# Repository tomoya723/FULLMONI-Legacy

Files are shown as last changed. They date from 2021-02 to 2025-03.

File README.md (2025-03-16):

### FULL-MONI フルモニ
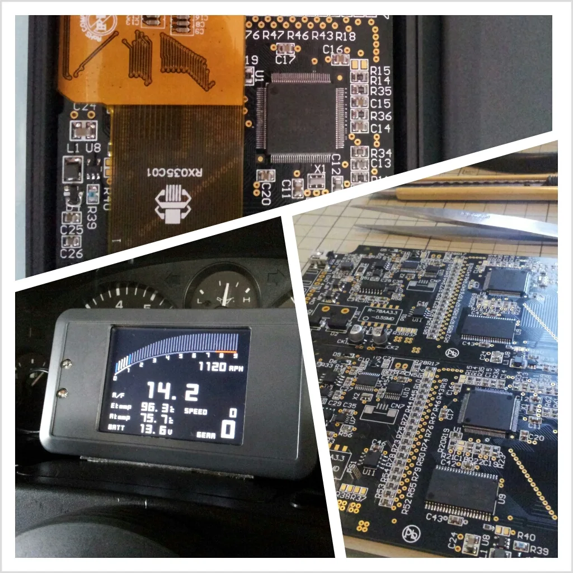
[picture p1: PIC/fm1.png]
fm1

## ０．注記
 - このリポジトリは過去に開発を行ったものを参考公開しています。
 - 回路に含む電子部品はディスコンも多く、再生産は困難です。
 - ファームウェアの更新の予定もありません。
## １．フルモニとは
 - フルコンモニターの略称で、「フルモニ」。
 - 各種フルコン（対応機種随時予定）やＤＥＦＩのコントロールユニットⅠ/Ⅱから取得したデータを
 - ３．５インチＴＦＴ液晶に数値やグラフとしてリアルタイム表示します。

 - 各データの取得は、
 - フルコンからのデータは、ＣＡＮまたはＲＳ２３２Ｃ信号ケーブルを接続し、
 - ＤＥＦＩコントロールユニットⅠ/Ⅱからのデータは、
 - フルモニ専用のメータリンクケーブルを接続することで、データを受信します。

 - 表示データはそれぞれの表示選択や、ピークホールド表示、ワーニング表示を行います。

## ２．設計概要
 - 基板　　:　３．５インチＴＦＴ液晶を備えた基板を設計する。
 - ケース　:　タカチ電機工業製ＬＣＳ形シリコンケース付プラスチックケースを使用。
 -  　　　　　液晶、ＬＥＤ及び入力端子部分の切削加工を行う。

## ３．ハードウェア仕様
 - １２Ｖバッテリー車向け制御電源（ＤＣ＋４．７５～＋３２Ｖ　→　内部電源＋３．３Ｖ）
 - タッチパネルＩＦ付３．５インチＴＦＴ液晶
 - 液晶バックライト用電源(調光機能付)
 - ＣＰＵ　ルネサステクノロジ　Ｈ８ＳＸ１６５５　４８ＭＨｚ
 - 外部ＳＲＡＭ　４Ｍｂｉｔ（おもに液晶用ビデオバッファ用途）
 - ＣＡＮ２．０Ｂ送受信　　　１チャンネル
 - ＲＳ２３２Ｃ送受信　　　　１チャンネル（ＦＣロガー接続選択機能付）
 - ＤＥＦＩ用Ｉ／Ｆ受信のみ　１チャンネル
 - 超高輝度ＬＥＤ（赤・橙）
 - ケース内ブザー
 - タッチパネルＩ／Ｆ
 - ＳＰＩフラッシュＲＯＭ　４ｋｂｉｔ

## ４．回路設計
 - 2013年1月28日更新
 - SCH : [FULLMONI_revC_SCH_20130128_101.pdf](https://github.com/tomoya723/FULLMONI-Legacy/blob/4514685d8f7103bcbfc3824f94381c39d037f4da/Hardware/FULLMONI_revC_SCH_20130128_101.pdf)<br>

## ５．基板設計
 - 2013年3月6日更新
 -  PCB : [FULLMONI_revC_PCB_20130306_101.pdf](https://github.com/tomoya723/FULLMONI-Legacy/blob/c4a8cc1ee19b74c6463b97665e4f9444e0cc6ba2/Hardware/FULLMONI_revC_PCB_20130306_101.pdf)<br>

## ５．ケース設計
 タカチ LC135-Nをベースに加工
 Case data: [LCケース加工図面20121030.pdf](https://github.com/tomoya723/FULLMONI-Legacy/blob/f6450ae8e5cbf89b6b0861b6293d36d16016387c/Hardware/LC%E3%82%B1%E3%83%BC%E3%82%B9%E5%8A%A0%E5%B7%A5%E5%9B%B3%E9%9D%A2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)<br>

## ６．基板作成仕様
 - 外形１３０．０ｍｍ×６６．０ｍｍ（但し外形はルーター加工特殊形状）
 - 板厚１．６ｍｍ
 - ＦＲ４(ガラスエポキシ)
 - 構成　４層（信号２層/電源２層）
 - 部品実装　片面　白色
 - レジスト　両面　黒色
 - 最小パタン幅０．２ｍｍ／最小クリアランス０．２ｍｍ
 - 最小穴径０．５ｍｍ
 - 無電解金フラッシュ仕上げ

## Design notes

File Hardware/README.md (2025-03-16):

# FULLMONI-Legacy：Hardware
# Schematic & PCB Files
 SCH : [FULLMONI_revC_SCH_20130128_101.pdf](https://github.com/tomoya723/FULLMONI-Legacy/blob/4514685d8f7103bcbfc3824f94381c39d037f4da/Hardware/FULLMONI_revC_SCH_20130128_101.pdf)<br>
 PCB : [FULLMONI_revC_PCB_20130306_101.pdf](https://github.com/tomoya723/FULLMONI-Legacy/blob/c4a8cc1ee19b74c6463b97665e4f9444e0cc6ba2/Hardware/FULLMONI_revC_PCB_20130306_101.pdf)<br>
 Gerver data: [CAM for FULLMONI_revC_20130306](https://github.com/tomoya723/FULLMONI-Legacy/tree/5013744d0d0d1694fd1f57bb33fa13641ba547d0/Hardware/CAM%20for%20FULLMONI_revC_20130306)<br>
 Metalmask data: [CAM for FULLMONI_revC_20130905_metalmask](https://github.com/tomoya723/FULLMONI-Legacy/tree/95ea076388679fc861d6b10b5c2362134d616c25/Hardware/CAM%20for%20FULLMONI_revC_20130905_metalmask)<br>
 Case data: [LCケース加工図面20121030.pdf](https://github.com/tomoya723/FULLMONI-Legacy/blob/f6450ae8e5cbf89b6b0861b6293d36d16016387c/Hardware/LC%E3%82%B1%E3%83%BC%E3%82%B9%E5%8A%A0%E5%B7%A5%E5%9B%B3%E9%9D%A2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)<br>

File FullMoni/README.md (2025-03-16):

# FULLMONI-Legacy : Firmware
## Development environment
- Renesas HEW
- H8SX Compiler
## State Machine Flow
 The FILLMONI-Legacy firmware is controlled by the following state machine flow in the main loop.<br>


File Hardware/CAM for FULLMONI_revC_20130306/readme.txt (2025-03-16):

<FILES>
readme.txt     : This file
FULLMONI.apr   : Apertures List
FULLMONI.GTL   : Top (component side) layer
FULLMONI.GTO   : Top Overlay (silkscreen)
FULLMONI.GTS   : Top Solder mask layer (Solder stop component side)
FULLMONI.GP1   : Mid plane1(GND)(Negative)
FULLMONI.GP2   : Mid plane2(POWER)(Negative)
FULLMONI.GBL   : Bottom (solder side) layer
FULLMONI.GBS   : Bottom Solder mask layer (Solder stop solder side)
FULLMONI.GM2   : Mechanical layers (Outline)
FULLMONI.GD1   : Drill tools
FULLMONI.GG1   : Drill guide
FULLMONI.DRR   : NCDrillReport
FULLMONI.DRL   : NCDrillOutput(EIA FILE)
FULLMONI.TXT   : NCDrillOutput(ASCII FILE)
FULLMONI.PDF   : Layer view

<LAYER STACK ORDER>
(top side)
   1. FULLMONI.GTL (Top layer)
   2. FULLMONI.GP1 (Mid plane 1)
   3. FULLMONI.GP2 (Mid plane 2)
   4. FULLMONI.GBL (Bottom layer)
(bottom side)

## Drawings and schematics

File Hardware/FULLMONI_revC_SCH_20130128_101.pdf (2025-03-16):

1 | 2 | 3 | 4 | 5 | 6 | 7 | 8

A

B

C

D

1 | 2 | 3 | 4 | 5 | 6 | 7 | 8

D

C

B

A

Title:

Size: | Number:
Date:

Revision:
Sheet of

A3

Designer:

0 3

Full-com Monitor

### 1 B

28-Jan-2013

tomoya

RESET

RxD6

RxD5
TxD5

RxD0
TxD0

SCK0

CS_CAN

INT_CAN
BL_PWM

RS

D[0-15]
A[1-18]

RD

CS2-A
RD/WR
CS1
LHWR
LLWR

TxD4
RxD4
SCK4
TP_CS

LCD_RST

SDA0
SCL0

INT_TP

FC_MODE

FULLMONI_1
FULLMONI_1.Sch

RxD5
TxD5
CS_CAN
SCK0
RxD0
TxD0
RESET
INT_CAN
BL_PWM
RxD6
FC_MODE

FULLMONI_2
FULLMONI_2.Sch

RD
LCD_RST
RS
CS2-A
RD/WR
CS1
LHWR
LLWR
D[0-15]
A[1-18]
TxD4
RxD4
SCK4
TP_CS
INT_TP
SDA0
SCL0

FULLMONI_3
FULLMONI_3.Sch

# P-O-R

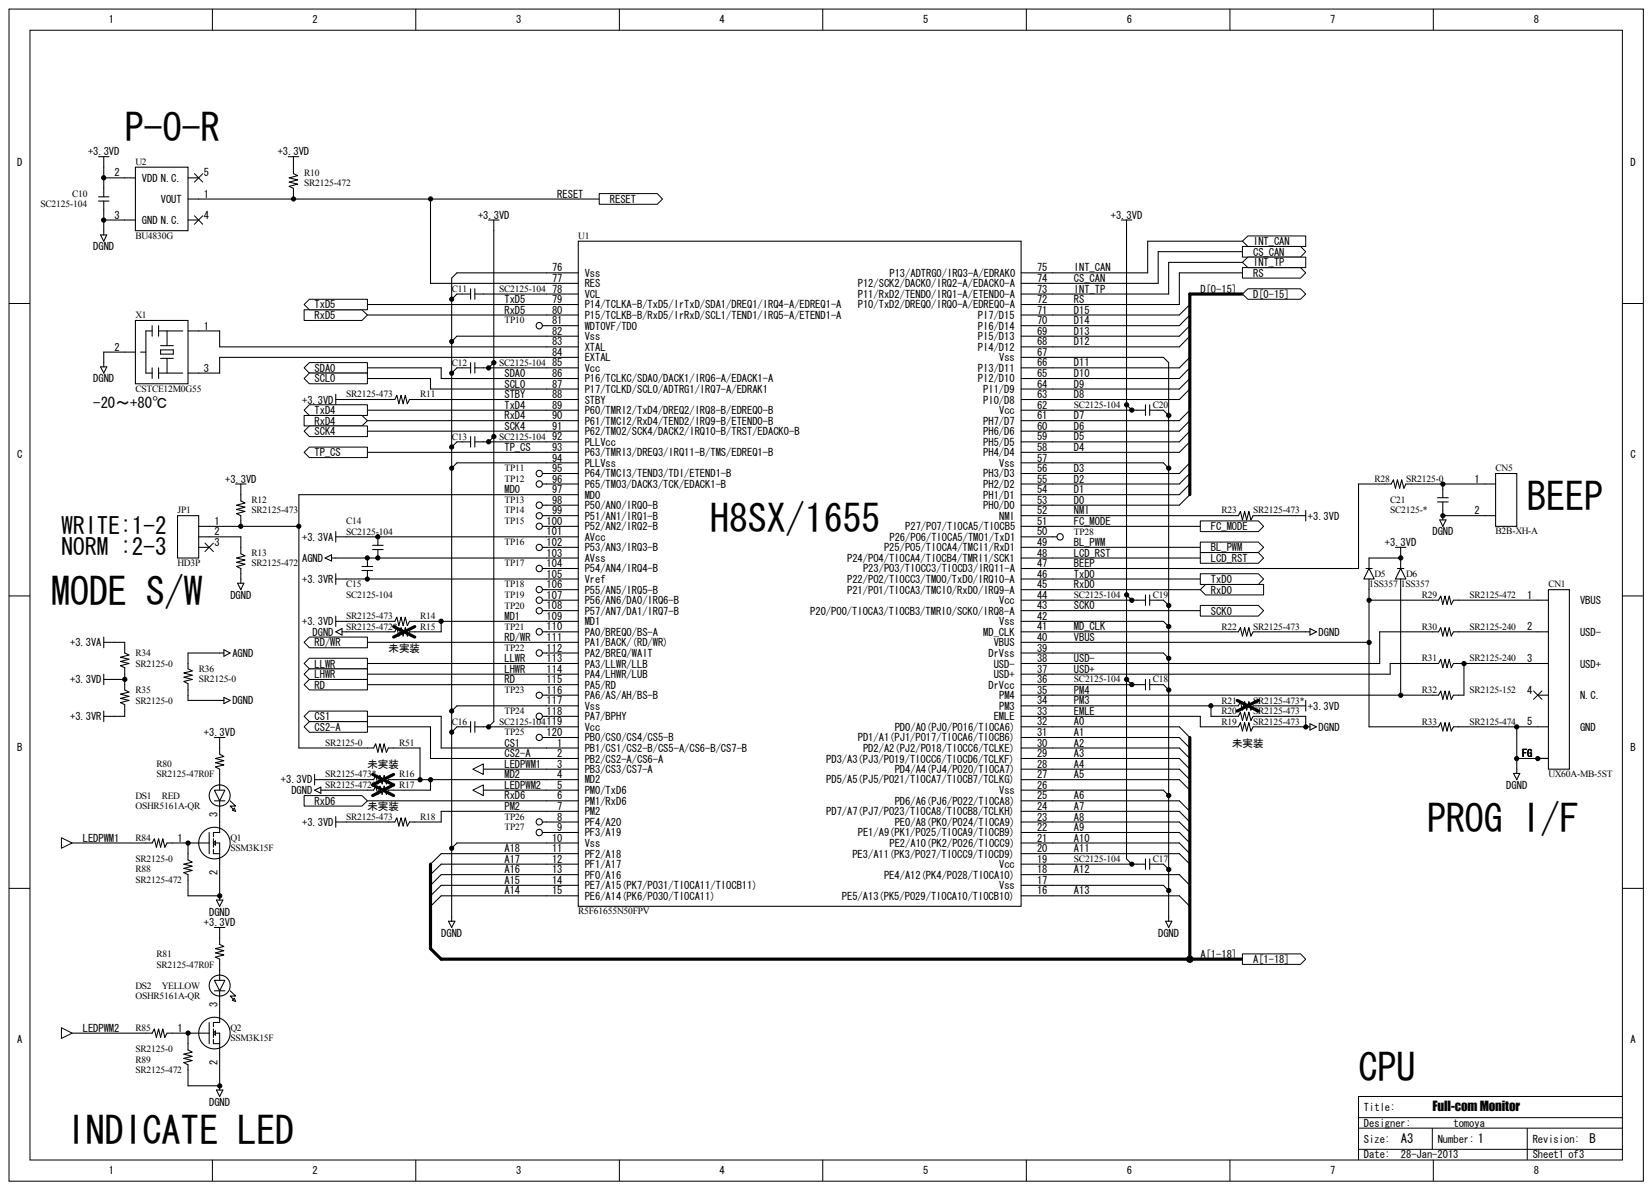
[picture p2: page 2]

# POWER

# POWER

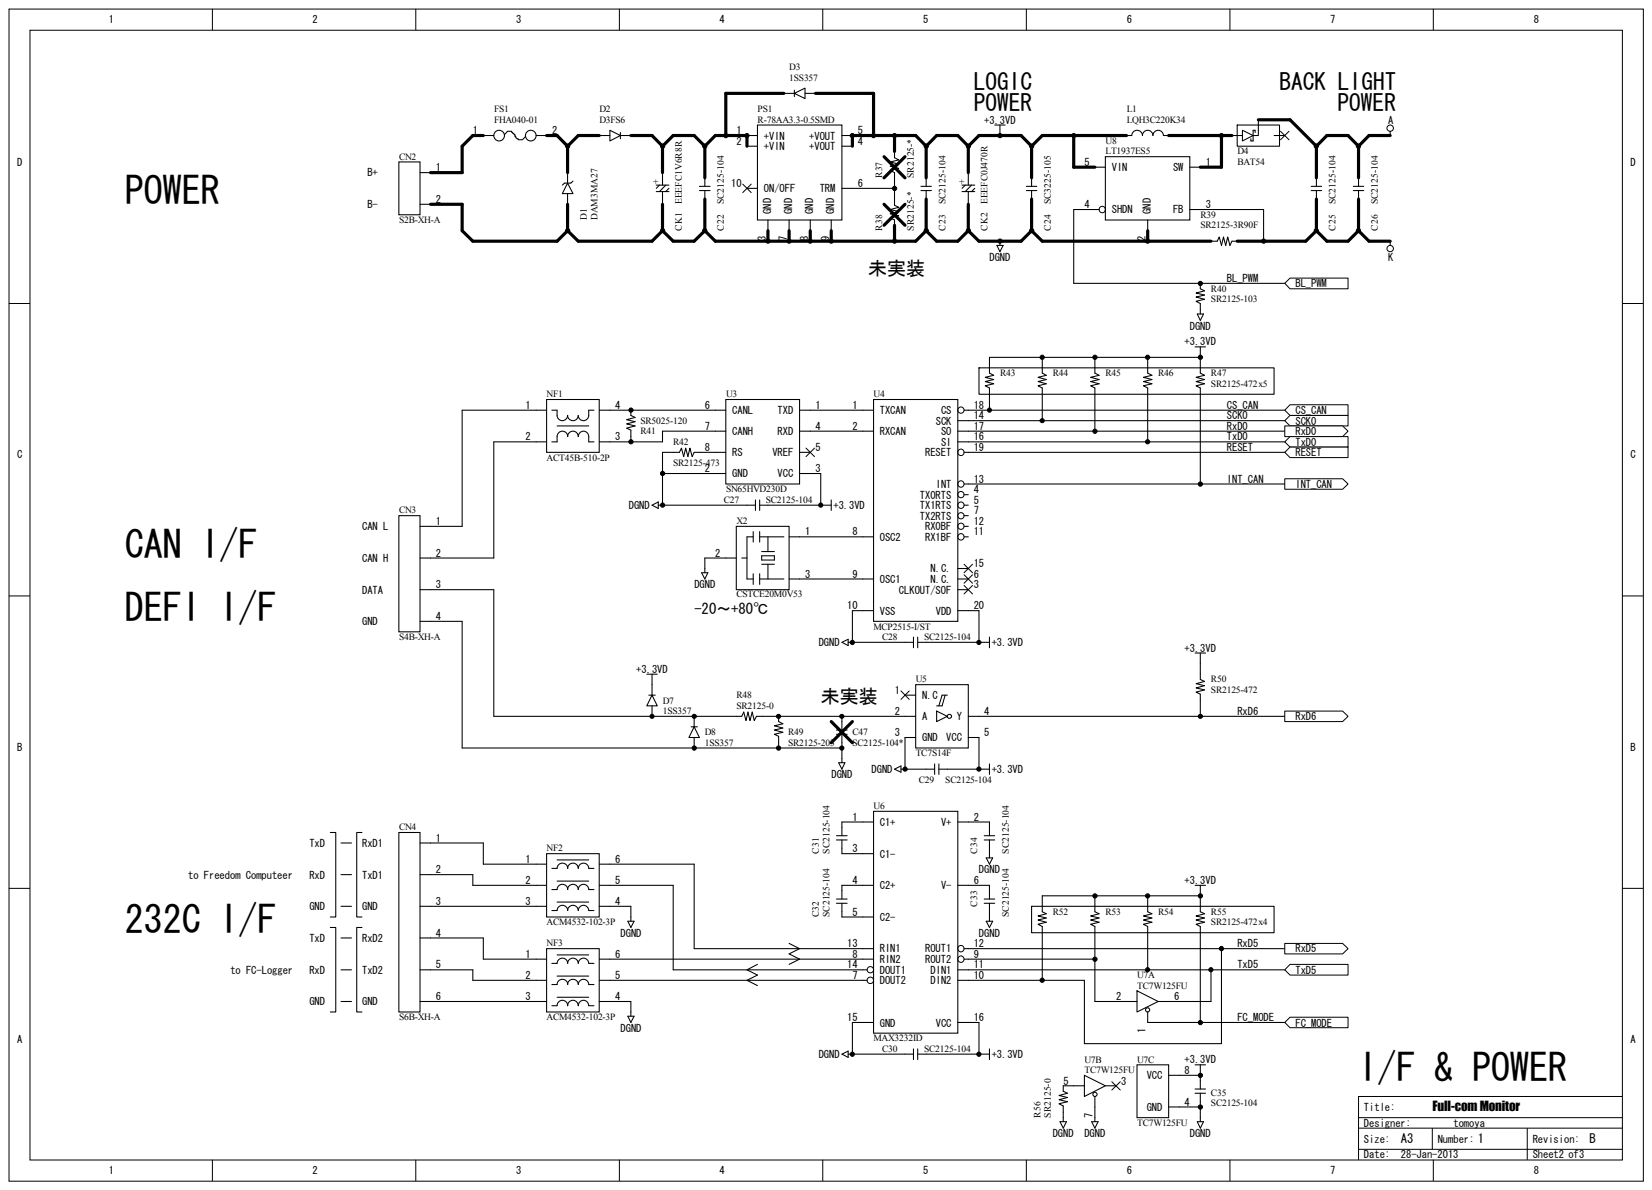
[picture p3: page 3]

LCD I/F | SRAM

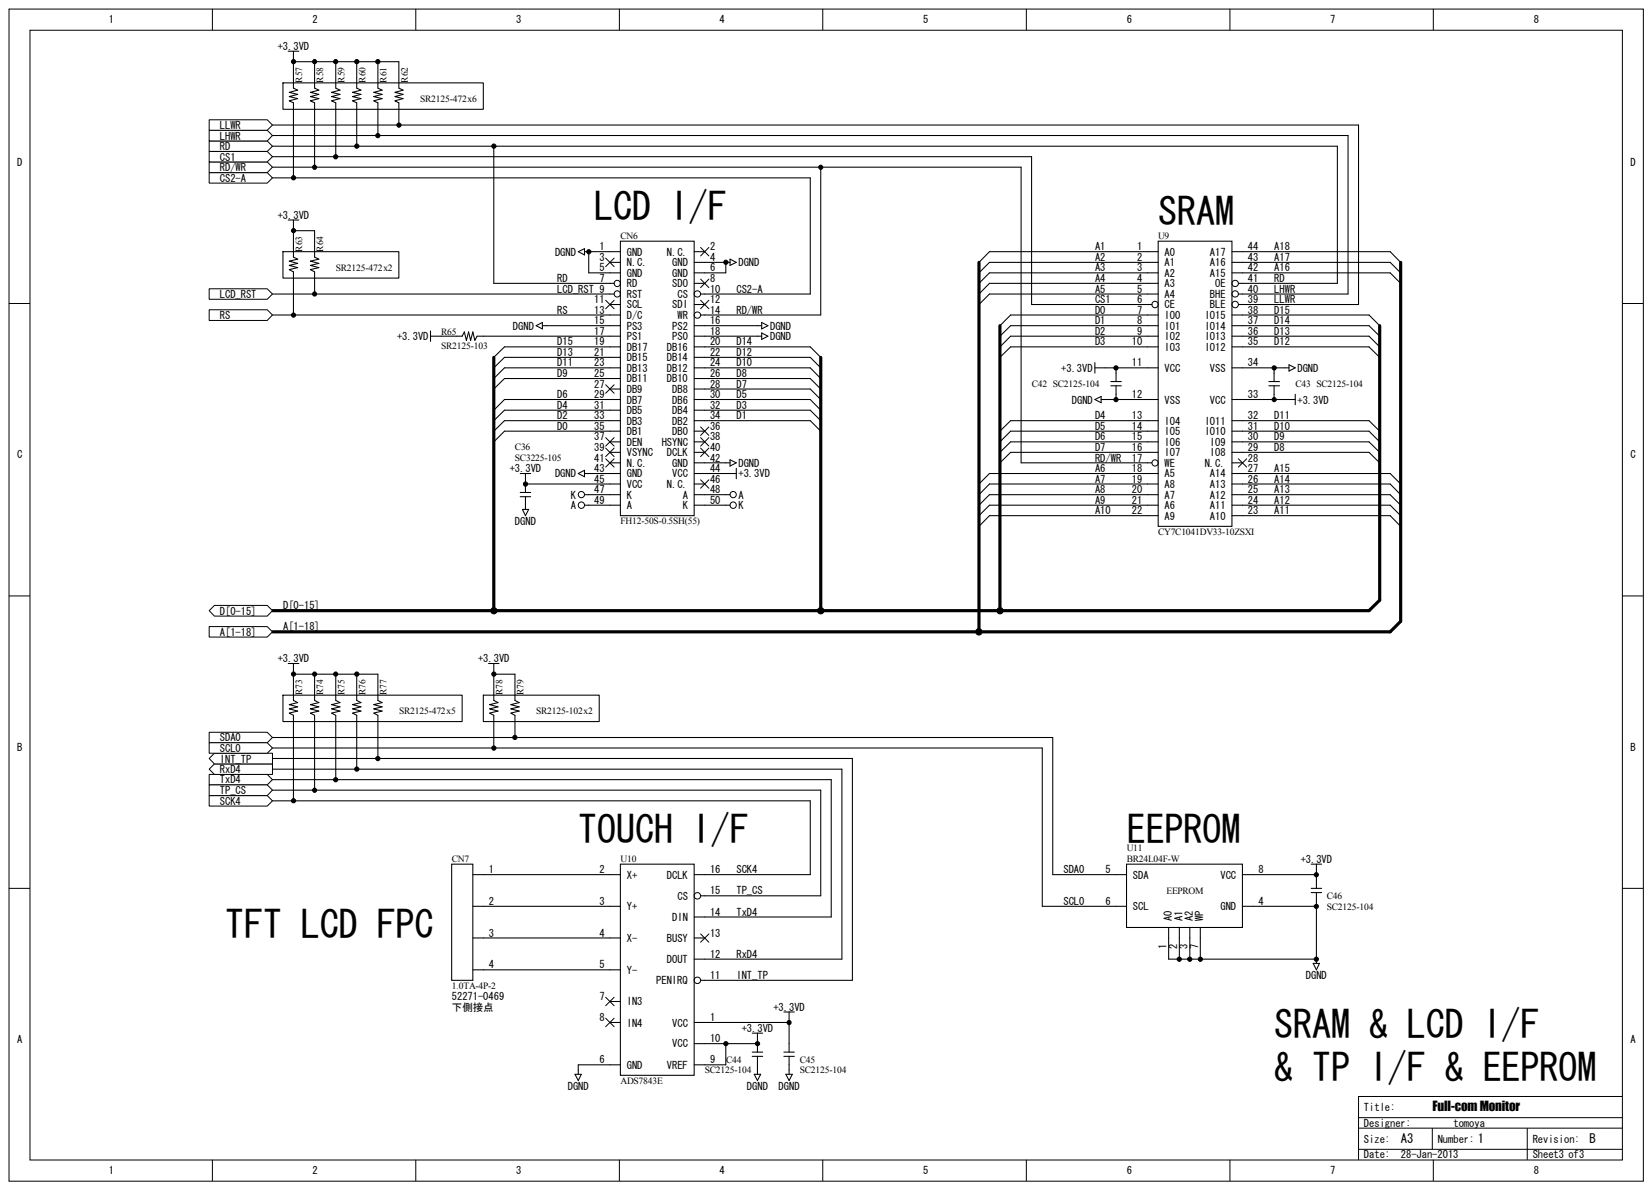
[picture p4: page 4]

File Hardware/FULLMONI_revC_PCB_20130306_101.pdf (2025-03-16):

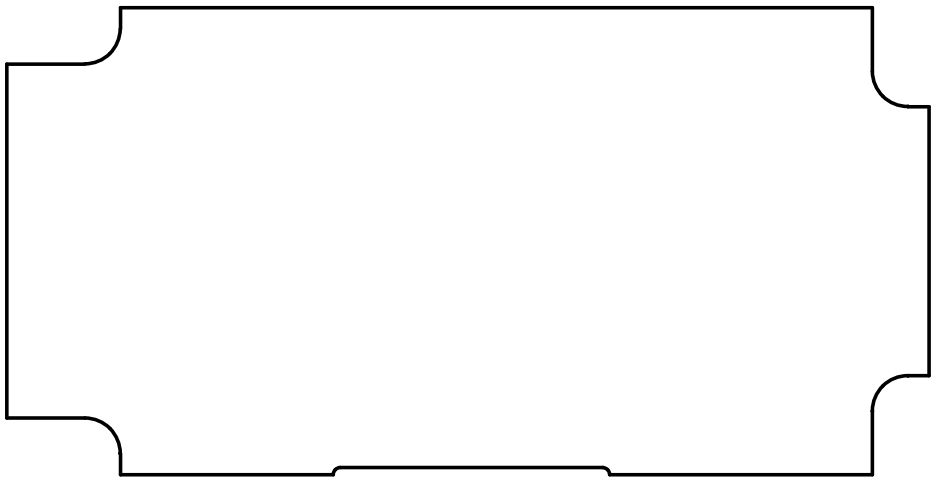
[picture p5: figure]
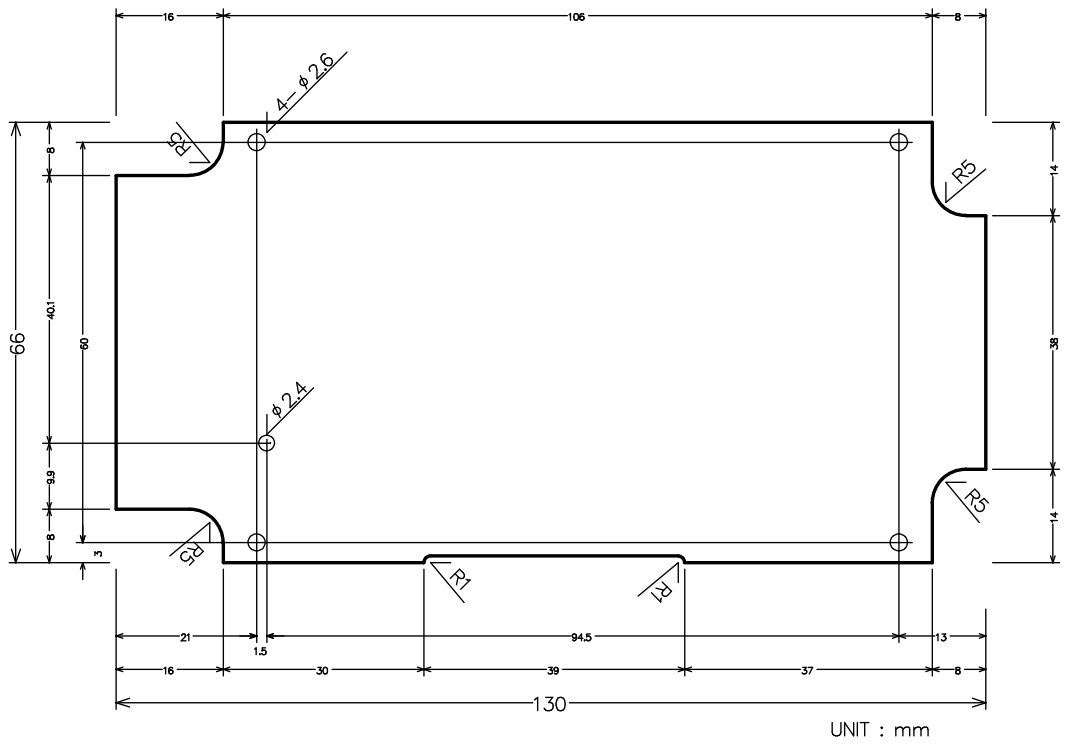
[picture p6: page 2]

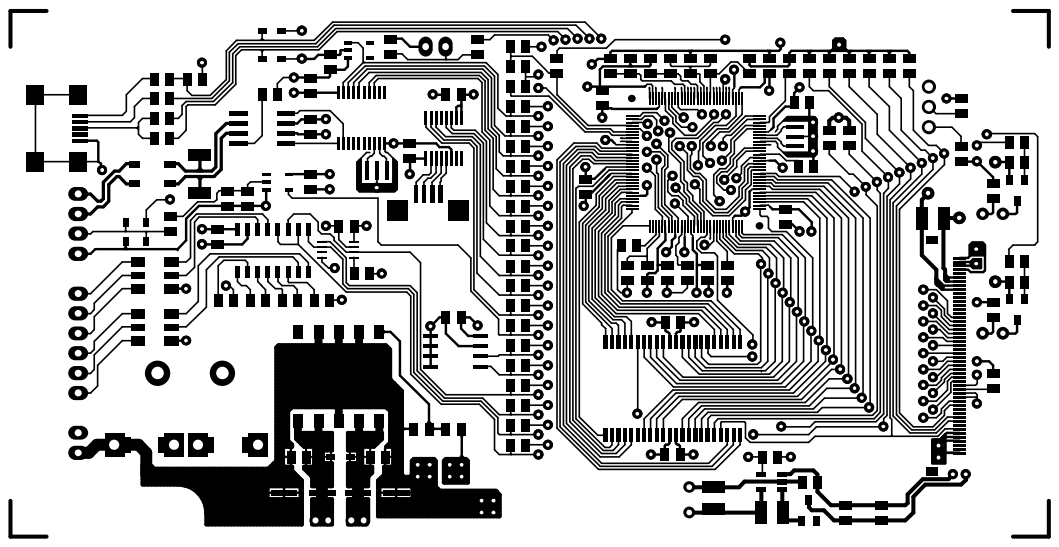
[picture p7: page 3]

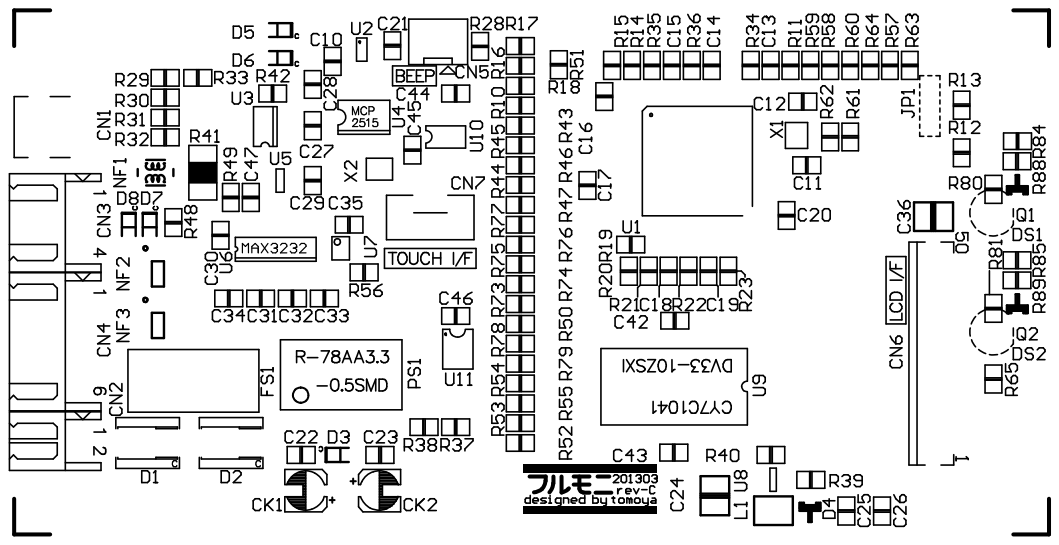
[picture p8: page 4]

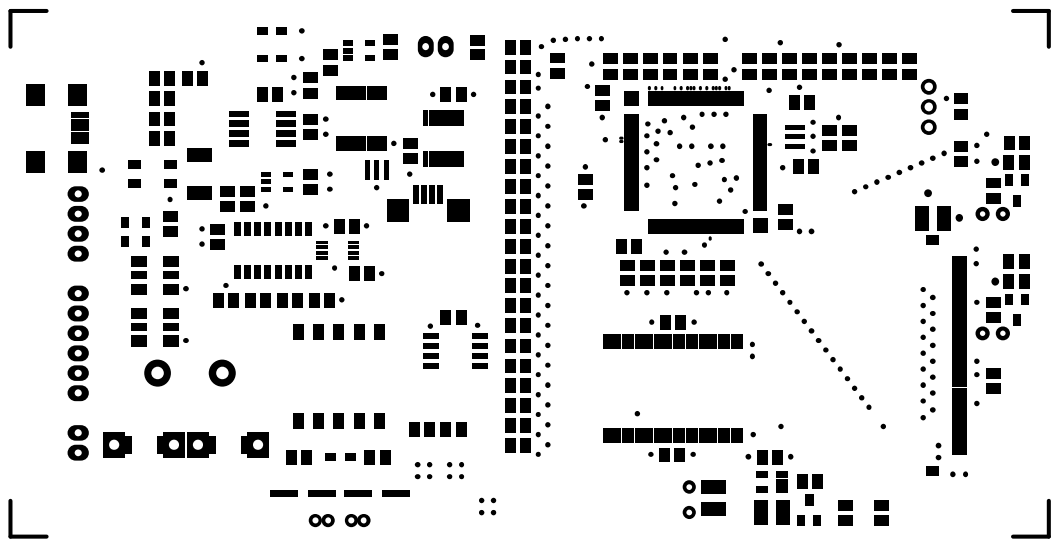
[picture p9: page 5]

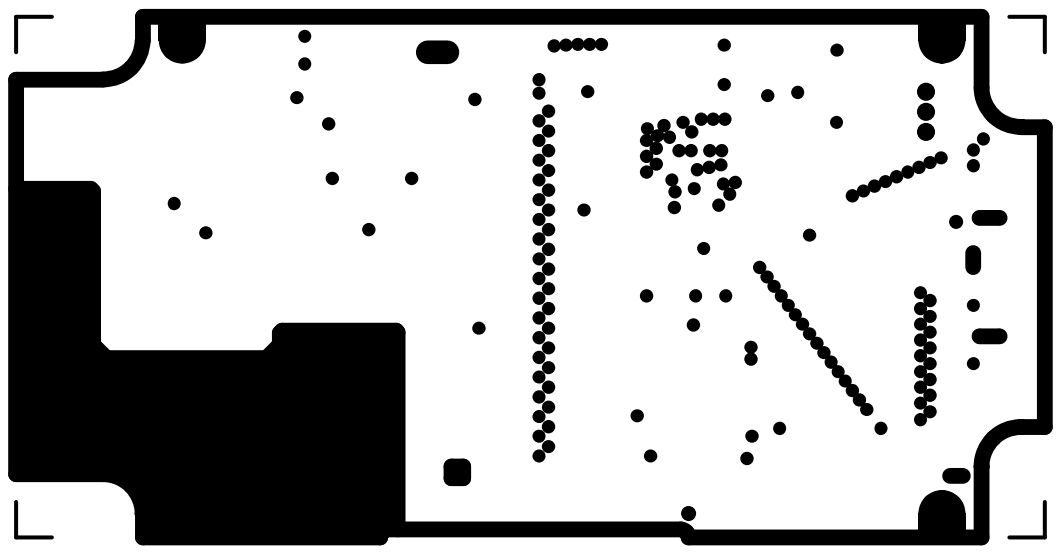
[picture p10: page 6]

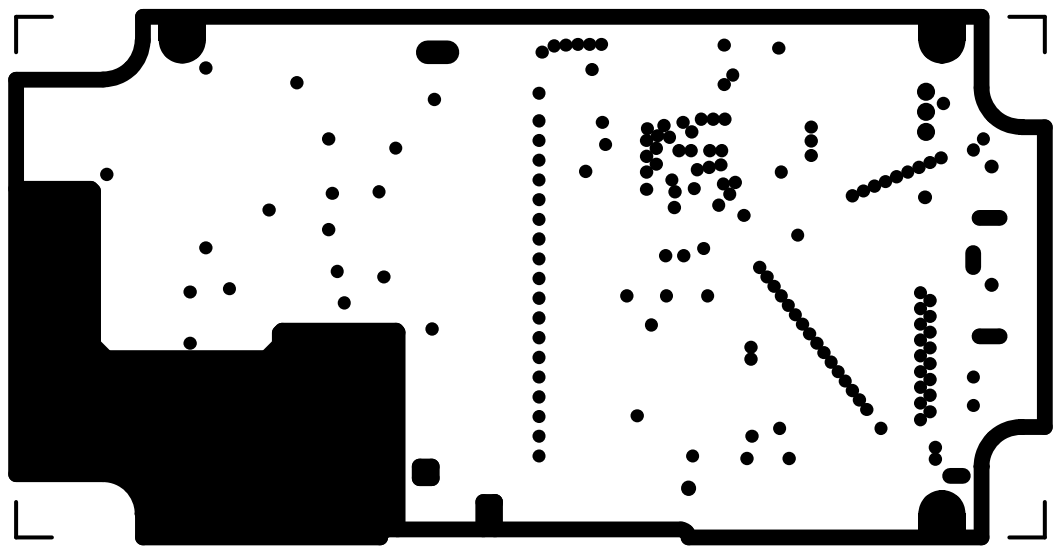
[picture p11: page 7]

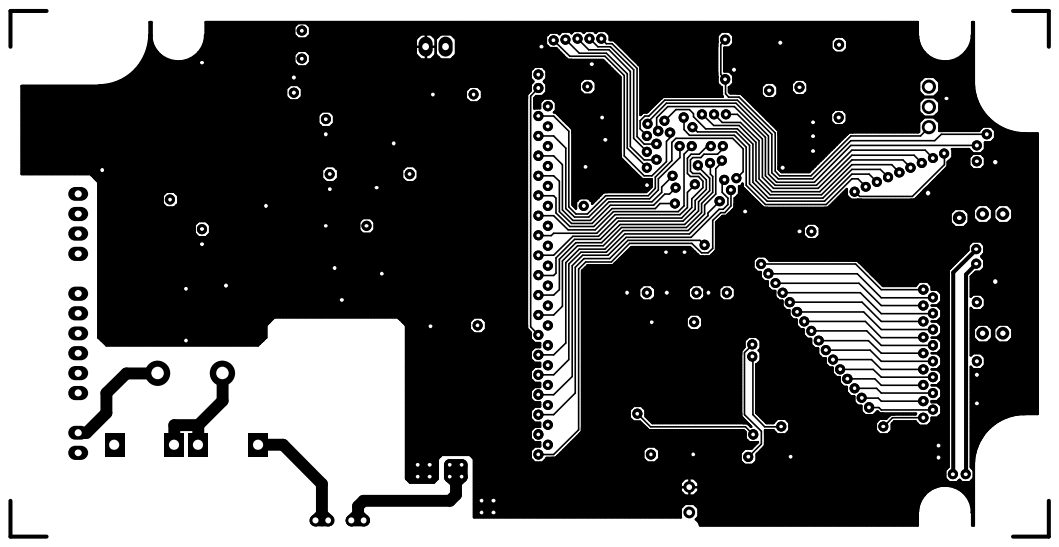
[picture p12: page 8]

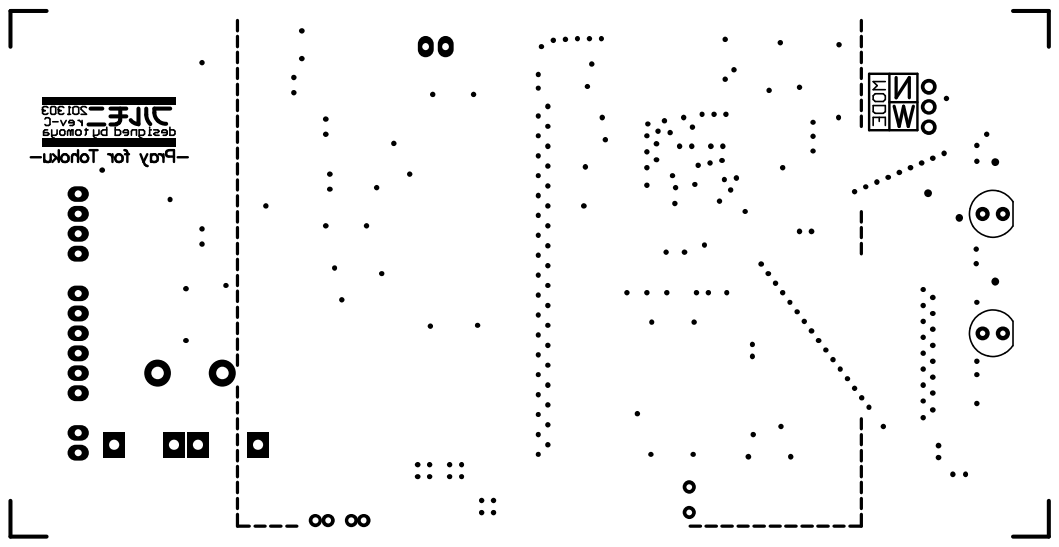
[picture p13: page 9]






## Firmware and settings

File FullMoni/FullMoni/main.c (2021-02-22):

// --------------------------------------------------------------------
// Copylight (C) 2021, Tomoya Sato( https://blog.goo.ne.jp/nacci_tomoya )
//
// This file is part of FullMoni firmwere.
//
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
// filename		:	main.c
// brief		:	FullMoni rev.C メインルーチン
// author		:	Tomoya Sato
// update		:	2021/02/21
// version		:	1.06
// --------------------------------------------------------------------

// --------------------------------------------------------------------
// プロトタイプ宣言
// --------------------------------------------------------------------
void main(void);
#ifdef __cplusplus
extern "C" {
void abort(void);
}
#endif

// --------------------------------------------------------------------
// システムヘッダファイル
// --------------------------------------------------------------------
//#include <machine.h>

// --------------------------------------------------------------------
// ユーザーヘッダファイル
// --------------------------------------------------------------------
#include "dataregister.h"
#include "iodefine.h"
#include "init_system.h"
#include "TFTLCD35.h"
#include "CAN2515.h"
#include "spi.h"
#include "state_control.h"

// --------------------------------------------------------------------
// グローバル変数宣言
// --------------------------------------------------------------------
volatile char version[5] = "v1.06";

// --------------------------------------------------------------------
// グローバル構造体宣言
// --------------------------------------------------------------------
volatile e2p_data_t			g_e2p_data;
volatile CAN_data_t			g_CAN_data;
volatile MoTeC1_data_t		g_MoTeC1_data;
volatile Haltech1_data_t	g_Haltech1_data;
volatile Haltech2_data_t	g_Haltech2_data;
volatile Freedom2_data_t	g_Freedom2_data;
volatile Megasquirt1_data_t	g_Megasquirt1_data;

// --------------------------------------------------------------------
// メインルーチン
// --------------------------------------------------------------------
void main(void)
{
	// --------------------------------------------------------------------
	// 各種機能初期化
	// --------------------------------------------------------------------
	Init_CPG();
	Init_INTC();
	Init_MSTP();
	Init_GPIO();
	Init_BSC();
	Init_EXDMAC();
	Init_DMAC();
	Init_TPU();
//	Init_UART();	//モデル別対応の為state_controlで実行
	Init_TFTLCD();
	Init_SPI();
//	Init_CAN();		//モデル別対応の為state_controlで実行
	Init_ADS7843();
	Init_IIC();
	
	// --------------------------------------------------------------------
	// データ初期化
	// --------------------------------------------------------------------
	Init_CAN_data();
	Init_MoTeC1_data();
	Init_Haltech1_data();
	Init_Haltech2_data();
	Init_Freedom2_data();
//	Init_MSquirt1_data();

	// --------------------------------------------------------------------
	// FONTデータ展開(Flash→内部RAM)
	// --------------------------------------------------------------------
	FONT_open();
	
	// --------------------------------------------------------------------
	// 初期ステート定義
	// --------------------------------------------------------------------
	A001();
	
	// --------------------------------------------------------------------
	// メインループ
	// --------------------------------------------------------------------
	while(1)
	{
		state_control();		// 状態別処理実行
	}
}

// --------------------------------------------------------------------
// インライン関数宣言
// --------------------------------------------------------------------
#pragma inline (Touch_Decision)
#pragma inline (Beep_OneShotMin_control)
#pragma inline (Beep_OneShotMax_control)
#pragma inline (Beep_TwoShotMin_control)

// --------------------------------------------------------------------
// インライン関数プロトタイプ宣言
// --------------------------------------------------------------------
static void Touch_Decision(void);
static void Beep_OneShotMin_control(void);
static void Beep_OneShotMax_control(void);
static void Beep_TwoShotMin_control(void);

// --------------------------------------------------------------------
// グローバル変数宣言
// --------------------------------------------------------------------
volatile long			g_int50mscnt;
volatile unsigned int	touch_done_flg;
volatile unsigned int	touch_drag_flg;
volatile unsigned int	g_PressX, g_PressY;
volatile unsigned int	g_DragX, g_DragY;
volatile unsigned int	g_refresh_done;
volatile unsigned int	g_led_o_max_flg;
volatile unsigned int	g_led_o_min_flg;
volatile unsigned int	g_led_r_max_flg;
volatile unsigned int	g_led_r_min_flg;
volatile unsigned int	g_can_rcv_timer;
volatile unsigned int	g_can_error_cnt;
static unsigned int		touch_cnt;
static unsigned int		Beep_OneShotMin_cnt;
static unsigned int		Beep_OneShotMax_cnt;
static unsigned int		Beep_TwoShotMin_cnt;
static unsigned int		master_warning_cnt;
static unsigned int		g_shift_timing_cnt;
static unsigned int		LEDonoff_cnt;

// --------------------------------------------------------------------
// MCP2515 CAN IRQ 外部割り込み
// --------------------------------------------------------------------
void Int_CAN2515(void)
{
	// --------------------------------------------------------------------
	// ローカル変数宣言
	// --------------------------------------------------------------------
	unsigned char CAN_rcv_INTF, can_rcv[14];
	signed short msgID;
	static unsigned int can_rcv_cnt;
	
	// --------------------------------------------------------------------
	// 割り込みフラグクリア
	// --------------------------------------------------------------------
	INTC.ISR.BIT.IRQ3F = 0;
	
	// --------------------------------------------------------------------
	// MCP2515割り込み要因別処理
	// --------------------------------------------------------------------
	CAN_rcv_INTF = CANReadReg(CANINTF);
	
//	if((CAN_rcv_INTF & 0x20) == 0x20)	// エラー割り込みフラグビット(EFLGレジスタの複数要因)確定
//	{
		g_can_error_cnt = CANReadReg(REC);	// 受信エラーカウンターストア
//	}
//	else
//	{
//		g_can_error_cnt = 0;
//	}
	
	if((CAN_rcv_INTF & 0x02) == 0x02)	// 受信バッファ1フル割り込みフラグビット確定
	{
		CANRxB1Read(&can_rcv[1], 8);
		
		msgID = MAKE_SID(can_rcv[1], can_rcv[2]);		// ID作成
		
		if(Onetime_Peakclear_cnt > 0) Onetime_Peakclear_cnt --;
		
		if			(g_e2p_data.E2P_1.model == CAN_std)
		{
				if		((msgID == g_e2p_data.E2P_1.CAN_ID1) && (g_e2p_data.E2P_1.CANcontrol.BIT.CAN_ch1 == 1))
				{
							g_CAN_data.ID1.DATA1				= ((((unsigned int) can_rcv[6] ) << 8) + can_rcv[7] );
							g_CAN_data.ID1.DATA2				= ((((unsigned int) can_rcv[8] ) << 8) + can_rcv[9] );
							g_CAN_data.ID1.DATA3				= ((((unsigned int) can_rcv[10]) << 8) + can_rcv[11]);
							g_CAN_data.ID1.DATA4				= ((((unsigned int) can_rcv[12]) << 8) + can_rcv[13]);
				}
				else if	((msgID == g_e2p_data.E2P_1.CAN_ID2) && (g_e2p_data.E2P_1.CANcontrol.BIT.CAN_ch2 == 1))
				{
							g_CAN_data.ID2.DATA1				= ((((unsigned int) can_rcv[6] ) << 8) + can_rcv[7] );
							g_CAN_data.ID2.DATA2				= ((((unsigned int) can_rcv[8] ) << 8) + can_rcv[9] );
							g_CAN_data.ID2.DATA3				= ((((unsigned int) can_rcv[10]) << 8) + can_rcv[11]);
							g_CAN_data.ID2.DATA4				= ((((unsigned int) can_rcv[12]) << 8) + can_rcv[13]);
				}
				else if	((msgID == g_e2p_data.E2P_1.CAN_ID3) && (g_e2p_data.E2P_1.CANcontrol.BIT.CAN_ch3 == 1))
				{
							g_CAN_data.ID3.DATA1				= ((((unsigned int) can_rcv[6] ) << 8) + can_rcv[7] );
							g_CAN_data.ID3.DATA2				= ((((unsigned int) can_rcv[8] ) << 8) + can_rcv[9] );
							g_CAN_data.ID3.DATA3				= ((((unsigned int) can_rcv[10]) << 8) + can_rcv[11]);
							g_CAN_data.ID3.DATA4				= ((((unsigned int) can_rcv[12]) << 8) + can_rcv[13]);
				}
				else if	((msgID == g_e2p_data.E2P_1.CAN_ID4) && (g_e2p_data.E2P_1.CANcontrol.BIT.CAN_ch4 == 1))
				{
							g_CAN_data.ID4.DATA1				= ((((unsigned int) can_rcv[6] ) << 8) + can_rcv[7] );
							g_CAN_data.ID4.DATA2				= ((((unsigned int) can_rcv[8] ) << 8) + can_rcv[9] );
							g_CAN_data.ID4.DATA3				= ((((unsigned int) can_rcv[10]) << 8) + can_rcv[11]);
							g_CAN_data.ID4.DATA4				= ((((unsigned int) can_rcv[12]) << 8) + can_rcv[13]);
				}
				else if	((msgID == g_e2p_data.E2P_1.CAN_ID5) && (g_e2p_data.E2P_1.CANcontrol.BIT.CAN_ch5 == 1))
				{
							g_CAN_data.ID5.DATA1				= ((((unsigned int) can_rcv[6] ) << 8) + can_rcv[7] );
							g_CAN_data.ID5.DATA2				= ((((unsigned int) can_rcv[8] ) << 8) + can_rcv[9] );
							g_CAN_data.ID5.DATA3				= ((((unsigned int) can_rcv[10]) << 8) + can_rcv[11]);
							g_CAN_data.ID5.DATA4				= ((((unsigned int) can_rcv[12]) << 8) + can_rcv[13]);
				}
				else if	((msgID == g_e2p_data.E2P_1.CAN_ID6) && (g_e2p_data.E2P_1.CANcontrol.BIT.CAN_ch6 == 1))
				{
							g_CAN_data.ID6.DATA1				= ((((unsigned int) can_rcv[6] ) << 8) + can_rcv[7] );
							g_CAN_data.ID6.DATA2				= ((((unsigned int) can_rcv[8] ) << 8) + can_rcv[9] );
							g_CAN_data.ID6.DATA3				= ((((unsigned int) can_rcv[10]) << 8) + can_rcv[11]);
							g_CAN_data.ID6.DATA4				= ((((unsigned int) can_rcv[12]) << 8) + can_rcv[13]);
				}
		
		}
		else if	(g_e2p_data.E2P_1.model == MoTeC1)
		{
			switch(msgID)
			{
				case 0x5F0:
							if(g_can_rcv_timer >= 10)		// 前回受信時から10mSec以上経過している場合
							{
									can_rcv_cnt = 0;		//  0 データ先頭
									g_MoTeC1_data.RPM					= ((((unsigned int) can_rcv[6] ) << 8) + can_rcv[7] );
									g_MoTeC1_data.ThrottlePosition		= ((((unsigned int) can_rcv[8] ) << 8) + can_rcv[9] );
									g_MoTeC1_data.ManifoldPressure		= ((((unsigned int) can_rcv[10]) << 8) + can_rcv[11]);
									g_MoTeC1_data.InletAirTemp			= ((((unsigned int) can_rcv[12]) << 8) + can_rcv[13]);
									can_rcv_cnt ++;
							}
							else
							{
								if		(can_rcv_cnt ==  1)	//  1
								{
									g_MoTeC1_data.EngineTemp			= ((((unsigned int) can_rcv[6] ) << 8) + can_rcv[7] );
									g_MoTeC1_data.Lambda1				= ((((unsigned int) can_rcv[8] ) << 8) + can_rcv[9] );
									g_MoTeC1_data.Lambda2				= ((((unsigned int) can_rcv[10]) << 8) + can_rcv[11]);
									g_MoTeC1_data.ExhaustPressure		= ((((unsigned int) can_rcv[12]) << 8) + can_rcv[13]);
									can_rcv_cnt ++;
								}
								else if	(can_rcv_cnt ==  2)	//  2
								{
									g_MoTeC1_data.MassAirFlow			= ((((unsigned int) can_rcv[6] ) << 8) + can_rcv[7] );
									g_MoTeC1_data.FuelTemp				= ((((unsigned int) can_rcv[8] ) << 8) + can_rcv[9] );
									g_MoTeC1_data.FuelPressure			= ((((unsigned int) can_rcv[10]) << 8) + can_rcv[11]);
									g_MoTeC1_data.OilTemp				= ((((unsigned int) can_rcv[12]) << 8) + can_rcv[13]);
									can_rcv_cnt ++;
								}
								else if	(can_rcv_cnt ==  3)	//  3
								{
									g_MoTeC1_data.OilPressure			= ((((unsigned int) can_rcv[6] ) << 8) + can_rcv[7] );
									// N/A								= ((((unsigned int) can_rcv[8] ) << 8) + can_rcv[9] );
									// N/A								= ((((unsigned int) can_rcv[10]) << 8) + can_rcv[11]);
									// N/A								= ((((unsigned int) can_rcv[12]) << 8) + can_rcv[13]);
									can_rcv_cnt ++;
								}
								else if	(can_rcv_cnt ==  4)	//  4
								{
									g_MoTeC1_data.ExhaustTemp1			= ((((unsigned int) can_rcv[6] ) << 8) + can_rcv[7] );
									g_MoTeC1_data.ExhaustTemp2			= ((((unsigned int) can_rcv[8] ) << 8) + can_rcv[9] );
									// N/A								= ((((unsigned int) can_rcv[10]) << 8) + can_rcv[11]);
									// N/A								= ((((unsigned int) can_rcv[12]) << 8) + can_rcv[13]);
									can_rcv_cnt ++;
								}
								else if	(can_rcv_cnt ==  5)	//  5
								{
									// N/A								= ((((unsigned int) can_rcv[6] ) << 8) + can_rcv[7] );
									// N/A								= ((((unsigned int) can_rcv[8] ) << 8) + can_rcv[9] );
									g_MoTeC1_data.BatteryVoltage		= ((((unsigned int) can_rcv[10]) << 8) + can_rcv[11]);
									g_MoTeC1_data.ECUTemp				= ((((unsigned int) can_rcv[12]) << 8) + can_rcv[13]);
									can_rcv_cnt ++;
								}
								else if	(can_rcv_cnt ==  6)	//  6
								{
									// N/A								= ((((unsigned int) can_rcv[6] ) << 8) + can_rcv[7] );
									// N/A								= ((((unsigned int) can_rcv[8] ) << 8) + can_rcv[9] );
									// N/A								= ((((unsigned int) can_rcv[10]) << 8) + can_rcv[11]);
									// N/A								= ((((unsigned int) can_rcv[12]) << 8) + can_rcv[13]);
									can_rcv_cnt ++;
								}
								else if	(can_rcv_cnt ==  7)	//  7
								{
									// N/A								= ((((unsigned int) can_rcv[6] ) << 8) + can_rcv[7] );
									g_MoTeC1_data.GroundSpeed			= ((((unsigned int) can_rcv[8] ) << 8) + can_rcv[9] );
									// N/A								= ((((unsigned int) can_rcv[10]) << 8) + can_rcv[11]);
									// N/A								= ((((unsigned int) can_rcv[12]) << 8) + can_rcv[13]);
									can_rcv_cnt ++;
								}
								else if	(can_rcv_cnt ==  8)	//  8
								{
									// N/A								= ((((unsigned int) can_rcv[6] ) << 8) + can_rcv[7] );
									// N/A								= ((((unsigned int) can_rcv[8] ) << 8) + can_rcv[9] );
									// N/A								= ((((unsigned int) can_rcv[10]) << 8) + can_rcv[11]);
									// N/A								= ((((unsigned int) can_rcv[12]) << 8) + can_rcv[13]);
									can_rcv_cnt ++;
								}
								else if	(can_rcv_cnt ==  9)	//  9
								{
									// N/A								= ((((unsigned int) can_rcv[6] ) << 8) + can_rcv[7] );
									g_MoTeC1_data.AimLambda1			= ((((unsigned int) can_rcv[8] ) << 8) + can_rcv[9] );
									g_MoTeC1_data.AimLambda2			= ((((unsigned int) can_rcv[10]) << 8) + can_rcv[11]);
									// N/A								= ((((unsigned int) can_rcv[12]) << 8) + can_rcv[13]);
									can_rcv_cnt ++;
								}
								else if	(can_rcv_cnt == 10)	// 10
								{
									// N/A								= ((((unsigned int) can_rcv[6] ) << 8) + can_rcv[7] );
									g_MoTeC1_data.IgnitionAdvance		= ((((unsigned int) can_rcv[8] ) << 8) + can_rcv[9] );
									// N/A								= ((((unsigned int) can_rcv[10]) << 8) + can_rcv[11]);
									// N/A								= ((((unsigned int) can_rcv[12]) << 8) + can_rcv[13]);
									can_rcv_cnt ++;
								}
								else if	(can_rcv_cnt == 11)	// 11
								{
									// N/A								= ((((unsigned int) can_rcv[6] ) << 8) + can_rcv[7] );
									// N/A								= ((((unsigned int) can_rcv[8] ) << 8) + can_rcv[9] );
									// N/A								= ((((unsigned int) can_rcv[10]) << 8) + can_rcv[11]);
									// N/A								= ((((unsigned int) can_rcv[12]) << 8) + can_rcv[13]);
									can_rcv_cnt ++;
								}
								else if	(can_rcv_cnt == 12)	// 12
								{
									// N/A								= ((((unsigned int) can_rcv[6] ) << 8) + can_rcv[7] );
									// N/A								= ((((unsigned int) can_rcv[8] ) << 8) + can_rcv[9] );
									// N/A								= ((((unsigned int) can_rcv[10]) << 8) + can_rcv[11]);
									// N/A								= ((((unsigned int) can_rcv[12]) << 8) + can_rcv[13]);
									can_rcv_cnt ++;
								}
								else if	(can_rcv_cnt == 13)	// 13
								{
									// N/A								= ((((unsigned int) can_rcv[6] ) << 8) + can_rcv[7] );
									// N/A								= ((((unsigned int) can_rcv[8] ) << 8) + can_rcv[9] );
									// N/A								= ((((unsigned int) can_rcv[10]) << 8) + can_rcv[11]);
									g_MoTeC1_data.InjectorDuty			= ((((unsigned int) can_rcv[12]) << 8) + can_rcv[13]);
									can_rcv_cnt ++;
								}
								else if	(can_rcv_cnt == 14)	// 14
								{
									g_MoTeC1_data.Gear					= ((((unsigned int) can_rcv[6] ) << 8) + can_rcv[7] );
									// N/A								= ((((unsigned int) can_rcv[8] ) << 8) + can_rcv[9] );
									// N/A								= ((((unsigned int) can_rcv[10]) << 8) + can_rcv[11]);
									// N/A								= ((((unsigned int) can_rcv[12]) << 8) + can_rcv[13]);
									can_rcv_cnt ++;
								}
								else if	(can_rcv_cnt == 15)	// 15
								{
									// N/A								= ((((unsigned int) can_rcv[6] ) << 8) + can_rcv[7] );
									// N/A								= ((((unsigned int) can_rcv[8] ) << 8) + can_rcv[9] );
									// N/A								= ((((unsigned int) can_rcv[10]) << 8) + can_rcv[11]);
									// N/A								= ((((unsigned int) can_rcv[12]) << 8) + can_rcv[13]);
									can_rcv_cnt ++;
								}
								else if	(can_rcv_cnt == 16)	// 16
								{
									// N/A								= ((((unsigned int) can_rcv[6] ) << 8) + can_rcv[7] );
									// N/A								= ((((unsigned int) can_rcv[8] ) << 8) + can_rcv[9] );
									// N/A								= ((((unsigned int) can_rcv[10]) << 8) + can_rcv[11]);
									// N/A								= ((((unsigned int) can_rcv[12]) << 8) + can_rcv[13]);
									can_rcv_cnt ++;
								}
								else if	(can_rcv_cnt == 17)	// 17
								{
									// N/A								= ((((unsigned int) can_rcv[6] ) << 8) + can_rcv[7] );
									// N/A								= ((((unsigned int) can_rcv[8] ) << 8) + can_rcv[9] );
									// N/A								= ((((unsigned int) can_rcv[10]) << 8) + can_rcv[11]);
									// N/A								= ((((unsigned int) can_rcv[12]) << 8) + can_rcv[13]);
									can_rcv_cnt ++;
								}
							}
							
							g_can_rcv_timer = 0;	// タイマーリセット
							default: break;
			}
		}
		else if	(g_e2p_data.E2P_1.model == MoTeC2)
		{
			switch(msgID)
			{
				case 0x0E8:
							if((can_rcv[6] == 0x82) && (can_rcv[7] == 0x81) && (can_rcv[8] == 0x80))
							{
								can_rcv_cnt = 0;
							}
							else
							{
								//
							}
							if		(can_rcv_cnt ==  0)	//  0
							{
								// N/A								= ((((unsigned int) can_rcv[6] ) << 8) + can_rcv[7] );
								// N/A								= ((((unsigned int) can_rcv[8] ) << 8) + can_rcv[9] );
								g_MoTeC1_data.RPM					= ((((unsigned int) can_rcv[10]) << 8) + can_rcv[11]);
								g_MoTeC1_data.ThrottlePosition		= ((((unsigned int) can_rcv[12]) << 8) + can_rcv[13]);
								can_rcv_cnt ++;
							}
							else if	(can_rcv_cnt ==  1)	//  1
							{
								g_MoTeC1_data.ManifoldPressure		= ((((unsigned int) can_rcv[6] ) << 8) + can_rcv[7] );
								g_MoTeC1_data.InletAirTemp			= ((((unsigned int) can_rcv[8] ) << 8) + can_rcv[9] );
								g_MoTeC1_data.EngineTemp			= ((((unsigned int) can_rcv[10]) << 8) + can_rcv[11]);
								g_MoTeC1_data.Lambda1				= ((((unsigned int) can_rcv[12]) << 8) + can_rcv[13]);
								can_rcv_cnt ++;
							}
							else if	(can_rcv_cnt ==  2)	//  2
							{
								g_MoTeC1_data.Lambda2				= ((((unsigned int) can_rcv[6] ) << 8) + can_rcv[7] );
								g_MoTeC1_data.ExhaustPressure		= ((((unsigned int) can_rcv[8] ) << 8) + can_rcv[9] );
								g_MoTeC1_data.MassAirFlow			= ((((unsigned int) can_rcv[10]) << 8) + can_rcv[11]);
								g_MoTeC1_data.FuelTemp				= ((((unsigned int) can_rcv[12]) << 8) + can_rcv[13]);
								can_rcv_cnt ++;
							}
							else if	(can_rcv_cnt ==  3)	//  3
							{
								g_MoTeC1_data.FuelPressure			= ((((unsigned int) can_rcv[6] ) << 8) + can_rcv[7] );
								g_MoTeC1_data.OilTemp				= ((((unsigned int) can_rcv[8] ) << 8) + can_rcv[9] );
								g_MoTeC1_data.OilPressure			= ((((unsigned int) can_rcv[10]) << 8) + can_rcv[11]);
								// N/A								= ((((unsigned int) can_rcv[12]) << 8) + can_rcv[13]);
								can_rcv_cnt ++;
							}
							else if	(can_rcv_cnt ==  4)	//  4
							{
								// N/A								= ((((unsigned int) can_rcv[6] ) << 8) + can_rcv[7] );
								// N/A								= ((((unsigned int) can_rcv[8] ) << 8) + can_rcv[9] );
								g_MoTeC1_data.ExhaustTemp1			= ((((unsigned int) can_rcv[10]) << 8) + can_rcv[11]);
								g_MoTeC1_data.ExhaustTemp2			= ((((unsigned int) can_rcv[12]) << 8) + can_rcv[13]);
								can_rcv_cnt ++;
							}
							else if	(can_rcv_cnt ==  5)	//  5
							{
								// N/A								= ((((unsigned int) can_rcv[6] ) << 8) + can_rcv[7] );
								// N/A								= ((((unsigned int) can_rcv[8] ) << 8) + can_rcv[9] );
								// N/A								= ((((unsigned int) can_rcv[10]) << 8) + can_rcv[11]);
								// N/A								= ((((unsigned int) can_rcv[12]) << 8) + can_rcv[13]);
								can_rcv_cnt ++;
							}
							else if	(can_rcv_cnt ==  6)	//  6
							{
								g_MoTeC1_data.BatteryVoltage		= ((((unsigned int) can_rcv[6] ) << 8) + can_rcv[7] );
								g_MoTeC1_data.ECUTemp				= ((((unsigned int) can_rcv[8] ) << 8) + can_rcv[9] );
								// N/A								= ((((unsigned int) can_rcv[10]) << 8) + can_rcv[11]);
								// N/A								= ((((unsigned int) can_rcv[12]) << 8) + can_rcv[13]);
								can_rcv_cnt ++;
							}
							else if	(can_rcv_cnt ==  7)	//  7
							{
								// N/A								= ((((unsigned int) can_rcv[6] ) << 8) + can_rcv[7] );
								// N/A								= ((((unsigned int) can_rcv[8] ) << 8) + can_rcv[9] );
								// N/A								= ((((unsigned int) can_rcv[10]) << 8) + can_rcv[11]);
								g_MoTeC1_data.GroundSpeed			= ((((unsigned int) can_rcv[12]) << 8) + can_rcv[13]);
								can_rcv_cnt ++;
							}
							else if	(can_rcv_cnt ==  8)	//  8
							{
								// N/A								= ((((unsigned int) can_rcv[6] ) << 8) + can_rcv[7] );
								// N/A								= ((((unsigned int) can_rcv[8] ) << 8) + can_rcv[9] );
								// N/A								= ((((unsigned int) can_rcv[10]) << 8) + can_rcv[11]);
								// N/A								= ((((unsigned int) can_rcv[12]) << 8) + can_rcv[13]);
								can_rcv_cnt ++;
							}
							else if	(can_rcv_cnt ==  9)	//  9
							{
								// N/A								= ((((unsigned int) can_rcv[6] ) << 8) + can_rcv[7] );
								// N/A								= ((((unsigned int) can_rcv[8] ) << 8) + can_rcv[9] );
								// N/A								= ((((unsigned int) can_rcv[10]) << 8) + can_rcv[11]);
								g_MoTeC1_data.AimLambda1			= ((((unsigned int) can_rcv[12]) << 8) + can_rcv[13]);
								can_rcv_cnt ++;
							}
							else if	(can_rcv_cnt == 10)	// 10
							{
								g_MoTeC1_data.AimLambda2			= ((((unsigned int) can_rcv[6] ) << 8) + can_rcv[7] );
								// N/A								= ((((unsigned int) can_rcv[8] ) << 8) + can_rcv[9] );
								// N/A								= ((((unsigned int) can_rcv[10]) << 8) + can_rcv[11]);
								g_MoTeC1_data.IgnitionAdvance		= ((((unsigned int) can_rcv[12]) << 8) + can_rcv[13]);
								can_rcv_cnt ++;
							}
							else if	(can_rcv_cnt == 11)	// 11
							{
								// N/A								= ((((unsigned int) can_rcv[6] ) << 8) + can_rcv[7] );
								// N/A								= ((((unsigned int) can_rcv[8] ) << 8) + can_rcv[9] );
								// N/A								= ((((unsigned int) can_rcv[10]) << 8) + can_rcv[11]);
								// N/A								= ((((unsigned int) can_rcv[12]) << 8) + can_rcv[13]);
								can_rcv_cnt ++;
							}
							else if	(can_rcv_cnt == 12)	// 12
							{
								// N/A								= ((((unsigned int) can_rcv[6] ) << 8) + can_rcv[7] );
								// N/A								= ((((unsigned int) can_rcv[8] ) << 8) + can_rcv[9] );
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

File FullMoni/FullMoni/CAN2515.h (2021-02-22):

// --------------------------------------------------------------------
// Copylight (C) 2021, Tomoya Sato( https://blog.goo.ne.jp/nacci_tomoya )
//
// This file is part of FullMoni firmwere.
//
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
// filename		:	CAN2515.h
// brief		:	FullMoni rev.C CAN管理
// author		:	Tomoya Sato
// update		:	2021/02/21
// version		:	1.06
// --------------------------------------------------------------------

// --------------------------------------------------------------------
// 多重インクルード防止
// --------------------------------------------------------------------
#ifndef _CAN2515_H_
#define _CAN2515_H_

// --------------------------------------------------------------------
// SPIポート ビット操作
// --------------------------------------------------------------------
#define CAN_SPI_CS_H	CAN_SPI_CS_PORT|=(1<<CAN_SPI_CS_BIT)
#define CAN_SPI_CS_L	CAN_SPI_CS_PORT&=~(1<<CAN_SPI_CS_BIT)

// --------------------------------------------------------------------
// CANビットレート
// --------------------------------------------------------------------
#define CAN_BRP_20MHz_1MBPS		0			// FOSC=20MHz
#define CAN_BRP_20MHz_500KBPS	1			// FOSC=20MHz
#define CAN_BRP_20MHz_250KBPS	3			// FOSC=20MHz
#define CAN_BRP_20MHz_125KBPS	4			// FOSC=20MHz

// --------------------------------------------------------------------
// SPIコマンド インストラクション
// --------------------------------------------------------------------
#define SPI_INST_RESET		0xC0
#define SPI_INST_READ		0x03
#define SPI_INST_WRITE		0x02
#define SPI_INST_RD_RXBUF	0xC0
#define SPI_INST_LD_TXBUF	0x40
#define SPI_INST_RTS		0x80
#define SPI_INST_RD_STAT	0xA0
#define SPI_INST_RX_STAT	0xB0
#define SPI_INST_BIT_MOD	0x05

// --------------------------------------------------------------------
// 送／受信バッファ シーケンシャル・リード／ライト インストラクション
// --------------------------------------------------------------------
#define RD_RXBUF_RXB0SIDH	0x90
#define RD_RXBUF_RXB0D0		0x92
#define RD_RXBUF_RXB1SIDH	0x94
#define RD_RXBUF_RXB1D0		0x96
#define LD_TXBUF_TXB0SIDH	0x40
#define LD_TXBUF_TXB0D0		0x41
#define LD_TXBUF_TXB1SIDH	0x42
#define LD_TXBUF_TXB1D0		0x43
#define LD_TXBUF_TXB2SIDH	0x44
#define LD_TXBUF_TXB2D0		0x45

// --------------------------------------------------------------------
// CAN ドライバ（マクロ）
// --------------------------------------------------------------------
// --------------------------------------------------------------------
// CANオペレーション・モード設定
// --------------------------------------------------------------------
#define CANSetOpMode(mode) CANBitModCmd(CANCTRL, 7<<5, mode<<5)

// --------------------------------------------------------------------
// 割り込み許可設定
// --------------------------------------------------------------------
#define RX0IE_Enable CANBitModCmd(CANINTE, 0x01, 0x01)
#define RX0IE_Disable CANBitModCmd(CANINTE, 0x01, 0x00)
#define RX1IE_Enable CANBitModCmd(CANINTE, 0x02, 0x02)
#define RX1IE_Disable CANBitModCmd(CANINTE, 0x02, 0x00)
#define TX0IE_Enable CANBitModCmd(CANINTE, 0x04, 0x04)
#define TX0IE_Disable CANBitModCmd(CANINTE, 0x04, 0x00)
#define TX1IE_Enable CANBitModCmd(CANINTE, 0x08, 0x08)
#define TX1IE_Disable CANBitModCmd(CANINTE, 0x08, 0x00)
#define TX2IE_Enable CANBitModCmd(CANINTE, 0x10, 0x10)
#define TX2IE_Disable CANBitModCmd(CANINTE, 0x10, 0x00)
#define ERRIE_Enable CANBitModCmd(CANINTE, 0x20, 0x20)
#define ERRIE_Disable CANBitModCmd(CANINTE, 0x20, 0x00)
#define WAKIE_Enable CANBitModCmd(CANINTE, 0x40, 0x40)
#define WAKIE_Disable CANBitModCmd(CANINTE, 0x40, 0x00)
#define MERRE_Enable CANBitModCmd(CANINTE, 0x80, 0x80)
#define MERRE_Disable CANBitModCmd(CANINTE, 0x80, 0x00)

// --------------------------------------------------------------------
// 割り込みフラグクリア
// --------------------------------------------------------------------
#define RX0IF_Clear CANBitModCmd(CANINTF, 0x01, 0x00)
#define RX1IF_Clear CANBitModCmd(CANINTF, 0x02, 0x00)
#define TX0IF_Clear CANBitModCmd(CANINTF, 0x04, 0x00)
#define TX1IF_Clear CANBitModCmd(CANINTF, 0x08, 0x00)
#define TX2IF_Clear CANBitModCmd(CANINTF, 0x10, 0x00)
#define ERRIF_Clear CANBitModCmd(CANINTF, 0x20, 0x00)
#define WAKIF_Clear CANBitModCmd(CANINTF, 0x40, 0x00)
#define MERRF_Clear CANBitModCmd(CANINTF, 0x80, 0x00)

#define RX0OVR_Clear CANBitModCmd(EFLG, 0x40, 0x00);
#define RX1OVR_Clear CANBitModCmd(EFLG, 0x80, 0x00);


// --------------------------------------------------------------------
// エラーカウンタクリア
// --------------------------------------------------------------------
#define TEC_Clear CANBitModCmd(TEC, 0xFF, 0x00)
#define REC_Clear CANBitModCmd(REC, 0xFF, 0x00)

// --------------------------------------------------------------------
// オペレーション・モード CANCTRL/CANSTAT
// --------------------------------------------------------------------
#define CAM_MODE_NORMAL		0
#define CAM_MODE_SLEEP		1
#define CAM_MODE_LOOPBACK	2
#define CAM_MODE_LISTEN		3
#define CAM_MODE_CONFIG		4

// --------------------------------------------------------------------
// レジスタ バイト・リード
// --------------------------------------------------------------------
#define CANReadReg(adrs) CANRegRead2B(SPI_INST_READ, adrs)

// --------------------------------------------------------------------
// ステータス・リード
// --------------------------------------------------------------------
#define CANReadStat() CANRegRead2B(SPI_INST_RD_STAT, 0)

// --------------------------------------------------------------------
// 受信ステータス・リード
// --------------------------------------------------------------------
#define CANReadRXStat() CANRegRead2B(SPI_INST_RX_STAT, 0)

// --------------------------------------------------------------------
// フィルタ・モードの設定
// --------------------------------------------------------------------
#define CANSetFilterRxB0(mode) CANWriteReg(RXB0CTRL, mode<<5)
#define CANSetFilterRxB1(mode) CANWriteReg(RXB1CTRL, mode<<5)
// --------------------------------------------------------------------
// mode
// --------------------------------------------------------------------
#define FILTER_MOD_ALL_HIT 3		// マスク、フィルタ使用せず
#define FILTER_MOD_SID_HIT 1		// SIDでマスク、フィルタ適用


// --------------------------------------------------------------------
// 受信バッファ シーケンシャル・リード
// --------------------------------------------------------------------
#define CANRxB0MsgRead(buf) CANTxRxBufRW(RD_RXBUF_RXB0SIDH, 1, buf, 5)
#define CANRxB1MsgRead(buf) CANTxRxBufRW(RD_RXBUF_RXB1SIDH, 1, buf, 5)
#define CANRxB0DatRead(buf) CANTxRxBufRW(RD_RXBUF_RXB0D0, 1, buf, 8)
#define CANRxB1DatRead(buf) CANTxRxBufRW(RD_RXBUF_RXB1D0, 1, buf, 8)

// --------------------------------------------------------------------
// 受信バッファ シーケンシャル・リード(メッセージ＋データ)
// --------------------------------------------------------------------
#define CANRxB0Read(buf, dsiz) CANTxRxBufRW(RD_RXBUF_RXB0SIDH, 1, buf, 5+dsiz)
#define CANRxB1Read(buf, dsiz) CANTxRxBufRW(RD_RXBUF_RXB1SIDH, 1, buf, 5+dsiz)
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

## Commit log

2013-03-20 フルモニファームウェアVer1.01
    ●CAN受信処理をハードウェアSPI(70Kbps)に変更。
    ●AFチャート表示追加
    ●表示値セミカスタム機能追加
    ・モデルおよび任意の数値内容をユーザーが選択できる機能を追加。
    ・カスタム内容を一括設定できる、モデル別プリセット機能を追加。
    ●ワーニング表示、マスターワーニング通知追加
    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
2013-03-31 フルモニファームウェアVer1.02
    ●Haltech2バグ修正
    ●起動シーケンスバグ修正
    ●SPIボーレート700Kbps→6Mbpsに変更
    ●内部画像色順番BGR→RGBに変更
    [ADS7843.h, CAN2515.c, CAN2515.h]
2013-06-16 フルモニ ファームウェアVer1.03
    ●フリーダムFC-03(空燃比) 対応 & 受信速度/内容切り替え機能追加
    ●MoTeC m84 対応
    ●MoTeC m100系をカスタムプリセットからMoTeC ADL互換電文に変更
2013-08-04 フルモニファームウェアVer1.04
    ●チャート画面に目標空燃比をプロット（※対応フルコンのみ）
    ●チャート画面に表示項目を任意に選べるバーゲージを追加
    ●チャート画面でマスターワーニング発報した場合、定常表示へ自動遷移
    ●ラベル項目に「MAF」「TARGET」「Baro-P」「S-1」～「S-9」「V-1」～「V-9」「T-1」～「T-9」を追加
    ●単位項目に「g」「m」「s」「d」を追加
2021-02-03 フルモニファームウェアVer1.05
    ●CAN受信に標準フォーマット受信機能追加
    ・ボーレート切り替え設定
    ・任意に設定可能な6種類のID設定と設定画面追加
    ・標準フォーマット専用の画面表示変数設定
    ※本対応織り込みにより、LINK G4+、LINK G4Xに対応
    ●CAN受信エラー表示追加
    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
2021-02-22 フルモニファームウェアVer1.06
    ●データラベルに「Ftemp」「MGP」を追加
2025-03-16 upload Hardware files
    [FULLMONI.DRL, FULLMONI.GBL, FULLMONI.GBP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]

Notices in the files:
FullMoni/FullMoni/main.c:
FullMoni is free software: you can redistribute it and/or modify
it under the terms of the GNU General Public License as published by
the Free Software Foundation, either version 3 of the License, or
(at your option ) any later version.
